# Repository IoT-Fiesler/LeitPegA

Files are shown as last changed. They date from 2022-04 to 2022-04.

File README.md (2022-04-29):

# LeitPegA
WiFi connected level meter using conductibility

To be honest, the principle is not new and there are already some descriptions of this kind of level measurement method for cisterns, wells and pump shafts on the Internet. However, what these COTS systems have in common is that the water level can only be read at fixed intervals when a button is pressed (to protect the batteries and prevent corrosion of or electrolysis on the electrodes). 

In the LeitPegA (Leitfaehigkeitsbasierte PegelAnzeige - conductivity-based level display) described here, this principle was combined with a Mega 2560 in order to enable evaluation by a microcontroller in addition to the graphic LED display via transistor circuit.
The levels are queried directly through the analog inputs of the Mega 2560. If the applied voltage exceeds a threshold value (0.7V due to the design), it evaluates this as "HIGH" and counts a variable upwards until this condition is no longer met. Then this loop breaks and the value of the variable is returned.

In addition, a potted KTY81-210 temperature sensor is installed in the cistern. These two values, the level and the water temperature, are shown on a Densitron PC-6749-AAW display in a three-second alternation.
In addition to being controlled via a button, the level can be measured using a UDP command via a WLAN connection using an ESP-01 module. In both cases, both the water level in percent and the temperature as an ASCII string are sent to the UDP server (home server) via UDP.

Another function of the LeitPegA is to switch from the cistern to the emergency feed tank if the level has dropped to 20 percent (or less). For this purpose, a solid-state relay is activated, which in turn operates a switching valve to enable water to be drawn from the emergency feed tank. To do this, the home server sends a corresponding UDP command to the LeitPegA in order to switch the relay on and off.

The device has been doing its job for almost a year now and works reliably for the most part. If, however, the water quality of the inlet is too good, i.e. the degree of pollution is too low, the resistance of the water is too high for a short time and the level returned is too low. However, this condition only lasts for a few hours, as existing deposits are loosened from the cistern walls and the resistance is reduced again.

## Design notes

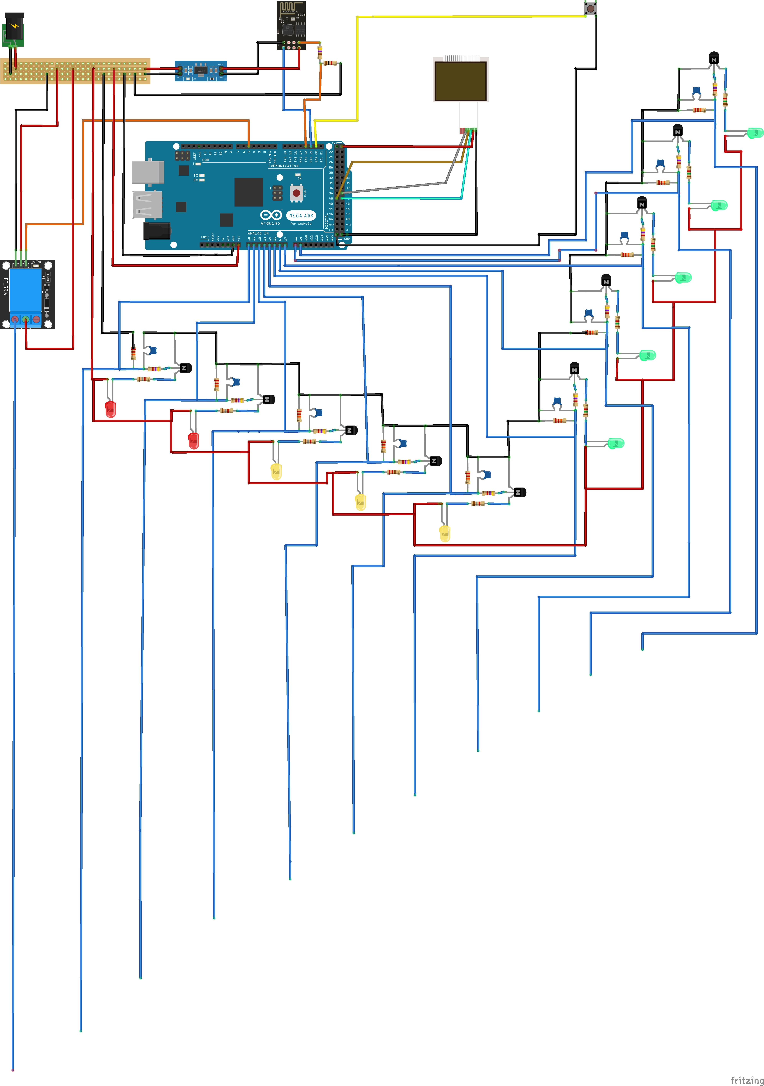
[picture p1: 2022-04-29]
LeitPegA_1_Diagram.jpg

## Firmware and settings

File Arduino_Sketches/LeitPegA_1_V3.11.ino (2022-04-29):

/*
  Number of versions:
  V1 - only push button, no display, only LEDs
  V2 - push button, LEDs and alternating display, measurement only when button is pushed
  V3 - push button, WiFi (UDP) via ESP-01 module on UART1, LEDs and display as under version 2
 
*/


/*Pin assignment

  Pins A0-A9: elektrodes level measurement
  Pin 20: push button (interrupt) for manual measurement
  Pins l8&19: UART 1 with interrupt for communication with ESP-01 module
  Pin 5: Relay
  Pin 6: Valve (via solid-state relay)
  Pin A10: KTY81-210 temperature sensor
  Pins 39-41: display


*/

//libraries
#include <Arduino.h>
#include <SPI.h>
#include <WiFiEsp.h>
#include <WiFiEspUdp.h>


int p = 0; // counting variable
int P = 0; // level in percentage
int T;  // temperature
int Offset = 5; // offset KTY81-210

//Variables and constants for Densitron LCD display

int CS = 39;
int DATA = 40;
int WR = 41;

// Pins fuer Relais
#define RELAIS 5 // Pin 5 for relay
#define VENTIL 6 // Pin 6 for valve-relay if P <= 10%

// Pin for push button
#define TASTER 20 // Pin 20 (Interrupt) for push button

// Pins for level measuring - 10 channels
#define BRAUN_10 22 //Pin 22 for brown wire & 10% level
#define WEISS_BRAUN_20 23 //Pin 23 for white (at brown) wire and 20% level
#define GELB_30 24 //Pin 24 for  yellow wire & 30% level
#define WEISS_GELB_40 25 // Pin 25 for white (at yellow) wire & 40% level
#define SCHWARZ_50 26 // Pin 26 for black wire & 50% level
#define WEISS_SCHWARZ_60 27 // Pin 27 for white (at black) wire & 60% level
#define BLAU_ROT_70 28 // Pin 28 for blue (at red) wire & 70% level
#define ROT_80 29 // Pin 29 for red wire & 80% level
#define BLAU_WEISS_90 30 // Pin 30 for blue (at white) wire & 90% level
#define WEISS_100 31 // Pinv 31 for white wire & 100% level


//Pins 11-13 for SPI or 50-52 respectively

#define CS_low()   digitalWrite(CS, LOW); delayMicroseconds(1)
#define CS_high()  delayMicroseconds(1); digitalWrite(CS, HIGH)
#define DATA(x)    if ((x)==0) digitalWrite(DATA, LOW); else digitalWrite(DATA, HIGH)
#define WR_pulse() digitalWrite(WR, LOW); delayMicroseconds(3); digitalWrite(WR, HIGH); delayMicroseconds(3)
//#define LED_on()   PORTB |= 0x20
//#define LED_off()  PORTB &= ~0x20

/* Definitions for the Densitron PC-6749 LCD glass (Pollin 120818)
   this is a 3-digit 16-segment LC display controlled by a HT1621

     glass segment mapping
   from the display datasheet  |  and how we use it

   ---------------------------
        | COM0 COM1 COM2 COM3
   -----+---------------------
   SEG0 | 1G   1K   1F   1E    \ lcd_buf[0] bit 0  1  2  3
   SEG1 | 1H   1L   1N   1D    /                4  5  6  7

   SEG2 | 1I   1M   1O   1P    \ lcd_buf[1] bit 0  1  2  3
   SEG3 | 1A   1J   1B   1C    /                4  5  6  7

   SEG4 |       X    Y    Z    \ lcd_buf[2] bit 0  1  2  3
   SEG5 | 2G   2K   2F   2E    /                4  5  6  7

   SEG6 | 2H   2L   2N   2D    \ lcd_buf[3] bit 0  1  2  3
   SEG7 | 2I   2M   2O   2P    /                4  5  6  7

   SEG8 | 2A   2J   2B   2C    \ lcd_buf[4] bit 0  1  2  3
   SEG9 | 3G   3K   3F   3E    /                4  5  6  7

   SEG10| 3H   3L   3N   3D    \ lcd_buf[5] bit 0  1  2  3
   SEG11| 3I   3M   3O   3P    /                4  5  6  7

   SEG12| 3A   3K   3B   3C    } lcd_buf[6] bit 0  1  2  3
   ---------------------------
*/

/*
   segment mapping table [digit][segment]
   entry is lcd_buf address in high nibble
   and bit number in low nibble
*/

const uint8_t segmap[3][16] =
{
  { 0x14, 0x16, 0x17, 0x07, 0x03, 0x02, 0x00, 0x04,
    0x10, 0x15, 0x01, 0x05, 0x11, 0x06, 0x12, 0x13
  },
  { 0x40, 0x42, 0x43, 0x33, 0x27, 0x26, 0x24, 0x30,
    0x34, 0x41, 0x25, 0x31, 0x35, 0x32, 0x36, 0x37
  },
  { 0x60, 0x62, 0x63, 0x53, 0x47, 0x46, 0x44, 0x50,
    0x54, 0x61, 0x45, 0x51, 0x55, 0x52, 0x56, 0x57
  }
};

/*
   font for 16-segment display
   it is sparse, hence organized as list
*/

const struct {
  char c;     /* the character */
  uint16_t s; /* 16 bits for segments A..P */
}  seg16font[] =
{ /* ABCDEFGHIJKLMNOP */
  { '1', 0b0110000001000000 },
  { '2', 0b1101110000111000 },
  { '3', 0b1111100000111000 },
  { '4', 0b0000001010111010 },
  { '5', 0b1011101000111000 },
  { '6', 0b1011111000111000 },
  { '7', 0b1000000001111010 },
  { '8', 0b1111111000111000 },
  { '9', 0b1111101000111000 },
  { '0', 0b1111111001010100 },
  { '+', 0b0000000010111010 },
  { '-', 0b0000000000111000 },
  { '*', 0b0000000111111111 },
  { '/', 0b0000000001010100 },
  { '.', 0b0000100000000000 },
  { '(', 0b0000000001000001 },
  { '$', 0b1011101010111010 },
  { ')', 0b0000000100000100 },
  { 'A', 0b1110011000111000 },
  { 'B', 0b1111100010011010 },
  { 'C', 0b1001111000000000 },
  { 'D', 0b1111100010010010 },
  { 'E', 0b1001111000110000 },
  { 'F', 0b1000011000110000 },
  { 'G', 0b1011111000001000 },
  { 'H', 0b0110011000111000 },
  { 'I', 0b1001100010010010 },
  { 'J', 0b1000100010010010 },
  { 'K', 0b0000000011010011 },
  { 'L', 0b0001111000000000 },
  { 'M', 0b0110011101010000 },
  { 'N', 0b0110011100010001 },
  { 'O', 0b1111111000000000 },
  { 'P', 0b1100011000111000 },
  { 'Q', 0b1111111000000001 },
  { 'R', 0b1100011000110001 },
  { 'S', 0b1011101000111000 },
  { 'T', 0b1000000010010010 },
  { 'U', 0b0111111000000000 },
  { 'V', 0b0000011001010100 },
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
  /* ABCDEFGHIJKLMNOP */
  { 0, 0xFFFF }
};

/*
   search character in font, return segments
   nonexisting character yields empty pattern
*/
uint16_t char2seg(char c)
{
  for (uint8_t j = 0; seg16font[j].c; j++) {
    if (seg16font[j].c == c) {
      return seg16font[j].s;
    }
  }
  return 0;
}


/*
   Send a command to the LCD controller
   ! we send the command code MSB first !
    so it matches the datasheet notation
*/
void lcd_cmd(uint8_t cmd) {
  CS_low();
  DATA(1); WR_pulse();
  DATA(0); WR_pulse();
  DATA(0); WR_pulse();
  uint8_t mask = 0x80;
  while (mask) {
    DATA(cmd & mask);
    WR_pulse();
    mask >>= 1;
  }
  DATA(1); WR_pulse();
  CS_high();
}

/*
   initialize and enable the LCD controller
*/
void lcd_init(void) {
  lcd_cmd(0b00000001); // system enable
  lcd_cmd(0b00101011); // 1/3 Bias, 4 commons
  lcd_cmd(0b00000011); // turn on LCD
}

/*
   the LCD buffer
*/
#define LCD_BUF_SIZE 7
uint8_t lcd_buf[LCD_BUF_SIZE];

/*
   clear LCD buffer
*/
void lcd_clear_buf(void)
{
  for (uint8_t i = 0; i < LCD_BUF_SIZE; i++) {
    lcd_buf[i] = 0;
  }
}

/*
   set segment bits from 'seg' for digit at position 'pos'
*/
void lcd_update_buf(uint8_t pos, uint16_t seg)
{
  uint8_t segno = 0;
  uint16_t mask = 0x8000;
  for ( ; segno < 16; segno++, mask >>= 1) {
    if (seg & mask) {
      uint8_t code = segmap[pos][segno];
      lcd_buf[code >> 4] |= 1 << (code & 7);
    }
  }
}

/*
   flush LCD buffer to the LCD controller
*/
void lcd_flush_buf(void) {
  CS_low();
  DATA(1); WR_pulse();
  DATA(0); WR_pulse();
  DATA(1); WR_pulse();

  /* address is always 0 (start of buffer) */
  DATA(0); WR_pulse();
  DATA(0); WR_pulse();
  DATA(0); WR_pulse();
  DATA(0); WR_pulse();
  DATA(0); WR_pulse();
  DATA(0); WR_pulse();

  /* bulk write the complete buffer */
  for (uint8_t i = 0; i < LCD_BUF_SIZE; i++) {
    uint8_t mask = 0x01;
    while (mask) {
      DATA(lcd_buf[i] & mask);
      WR_pulse();
      mask <<= 1;
    }
  }
  DATA(1);
  CS_high();
}


char ssid[] = "YOUR_SSID";            // your network SSID (name)
char pass[] = "YOUR_PASS";        // your network password
int status = WL_IDLE_STATUS;     // the Wifi radio's status

IPAddress ip(192, 168, 178, 91);

IPAddress RecipientIP(192, 168, 178, 56);

unsigned int RecipientPort = 9292;

unsigned int localPort = 8282;  // local port to listen on

char packetBuffer[255];          // buffer to hold incoming packet
char ReplyBuffer[] = "ACK";      // a string to send back

WiFiEspUDP Udp;

//int packetSize = Udp.parsePacket();

void setup() {

  pinMode(BRAUN_10, INPUT);
  pinMode(WEISS_BRAUN_20, INPUT);
  pinMode(GELB_30, INPUT);
  pinMode(WEISS_GELB_40, INPUT);
  pinMode(SCHWARZ_50, INPUT);
  pinMode(WEISS_SCHWARZ_60, INPUT);
  pinMode(BLAU_ROT_70, INPUT);
  pinMode(ROT_80, INPUT);
  pinMode(BLAU_WEISS_90, INPUT);
  pinMode(WEISS_100, INPUT);

  pinMode (RELAIS, OUTPUT);
  pinMode (VENTIL, OUTPUT);

  pinMode (TASTER, INPUT_PULLUP);

  // initialize serial for debugging
  Serial.begin(9600);
  // initialize serial for ESP module
  Serial1.begin(115200);
  // initialize ESP module
  WiFi.init(&Serial1);

  // check for the presence of the shield:
  if (WiFi.status() == WL_NO_SHIELD) {
    Serial.println("WiFi shield not present");
    // don't continue:
    while (true);
  }

  // attempt to connect to WiFi network
  while ( status != WL_CONNECTED) {
    Serial.print("Attempting to connect to WPA SSID: ");
    Serial.println(ssid);
    // Connect to WPA/WPA2 network
    status = WiFi.begin(ssid, pass);
  }
  
  Serial.println("Connected to wifi");
  printWifiStatus();

  Serial.println("\nStarting connection to server...");
  // if you get a connection, report back via serial:
  Udp.begin(localPort);
  
  Serial.print("Listening on port ");
  Serial.println(localPort);

  //Setup for Densitron LCD Display

  pinMode(CS,   OUTPUT);
  pinMode(WR,   OUTPUT);
  pinMode(DATA, OUTPUT);
  pinMode(LED_BUILTIN, OUTPUT);

  lcd_init();

  //delay(2000);
}

void loop () {

// if there's data available, read a packet
  int packetSize = Udp.parsePacket();
  if (packetSize) {
    Serial.print("Received packet of size ");
    Serial.println(packetSize);
    Serial.print("From ");
    IPAddress remoteIp = Udp.remoteIP();
    Serial.print(remoteIp);
    Serial.print(", port ");
    Serial.println(Udp.remotePort());

    // read the packet into packetBufffer
    int len = Udp.read(packetBuffer, 255);
    if (len > 0) {
      packetBuffer[len] = 0;
    }
    Serial.println("Contents:");
    Serial.println(packetBuffer);

    evalSerialData(packetBuffer);
  }

  else if (digitalRead(TASTER) == LOW) {  // if push button is on LOW ...

    Fuellstand();
    /*
        digitalWrite(RELAIS, HIGH); // Setze Relaisausgang auf HIGH

        p=0; // reset of level for new measurement
        P=0;

        delay(2000); // time for the capacitor to get fully charged

        for (int channel = 0; channel<=9; channel++){
          if (analogRead(channel) > 100) { //benchmark at 100, precisely with 0,7V @ 140

          int a;
          a=analogRead(channel);

          Serial.print("A");
          Serial.print(channel);
          Serial.print(":");
          Serial.println(a);

          p++;

          }
        else
        {
          break;
        }
      }
    */
    Serial.print("p=");
    Serial.println(p);

    //p=f;

    //p=Fuellstand();
    P = 10 * p;

    Serial.print("Pegelhöhe: ");
    Serial.print(P);
    Serial.println("%");

    // delay(1000);

    Temperatur();

    /*
        float X, R, T1;

        X = analogRead(A10);

        R = ((1023/X) - 1)*(1800);

        T1 = ((R - 1625)/15);

        T =(int) T1 - Offset;


      //  t = Temperatur;

        Serial.print("X=");
        Serial.println(X);
        Serial.print("R=");
        Serial.println(R);
        Serial.print("T1=");
        Serial.println(T1);
        Serial.print("Temperatur: ");
        Serial.print(T);
        Serial.println("°C");

    */

    String Ausgabe = "P" + String(P) + "%" + "," + "T" + String(T) + "G";

    //Serial3.println(Ausgabe);
    UDPsend(Ausgabe);

    /*
      Serial3.print("P");
      Serial3.print(P);
      Serial3.println("%");


      Serial3.print("T");
      Serial3.print(T);
      Serial3.println("G");
    */

    if (p == 10) {
      lcd_clear_buf();
      lcd_update_buf(0, char2seg('1'));
      lcd_update_buf(1, char2seg('0'));
      lcd_update_buf(2, char2seg('0'));
      lcd_flush_buf();
    }

    else if (p == 9) {
      lcd_clear_buf();
      lcd_update_buf(0, char2seg('P'));
      lcd_update_buf(1, char2seg('9'));
      lcd_update_buf(2, char2seg('0'));
      lcd_flush_buf();
    }
    else if (p == 8) {
      lcd_clear_buf();
      lcd_update_buf(0, char2seg('P'));
      lcd_update_buf(1, char2seg('8'));
      lcd_update_buf(2, char2seg('0'));
      lcd_flush_buf();
    }
    else if (p == 7) {
      lcd_clear_buf();
      lcd_update_buf(0, char2seg('P'));
      lcd_update_buf(1, char2seg('7'));
      lcd_update_buf(2, char2seg('0'));
      lcd_flush_buf();
    }
    else if (p == 6) {
      lcd_clear_buf();
      lcd_update_buf(0, char2seg('P'));
      lcd_update_buf(1, char2seg('6'));
      lcd_update_buf(2, char2seg('0'));
      lcd_flush_buf();
    }
    else if (p == 5) {
      lcd_clear_buf();
      lcd_update_buf(0, char2seg('P'));
      lcd_update_buf(1, char2seg('5'));
      lcd_update_buf(2, char2seg('0'));
      lcd_flush_buf();
    }
    else if (p == 4) {
      lcd_clear_buf();
      lcd_update_buf(0, char2seg('P'));
      lcd_update_buf(1, char2seg('4'));
      lcd_update_buf(2, char2seg('0'));
      lcd_flush_buf();
    }
    else if (p == 3) {
      lcd_clear_buf();
      lcd_update_buf(0, char2seg('P'));
      lcd_update_buf(1, char2seg('3'));
      lcd_update_buf(2, char2seg('0'));
      lcd_flush_buf();
    }
    else if (p == 2) {
      lcd_clear_buf();
      lcd_update_buf(0, char2seg('P'));
      lcd_update_buf(1, char2seg('2'));
      lcd_update_buf(2, char2seg('0'));
      lcd_flush_buf();
    }
    else if (p == 1) {
      lcd_clear_buf();
      lcd_update_buf(0, char2seg('P'));
      lcd_update_buf(1, char2seg('1'));
      lcd_update_buf(2, char2seg('0'));
      lcd_flush_buf();
    }

    delay (2000);

    int t1, t2;

    t1 = (int) T / 10;
    t2 = T - 10 * t1;

    lcd_clear_buf();
    lcd_update_buf(0, char2seg('T'));

    if (t1 == 2) {
      lcd_update_buf(1, char2seg('2'));
    }
    else if (t1 == 1) {
      lcd_update_buf(1, char2seg('1'));
    }
    else if (t1 == 0) {
      lcd_update_buf(1, char2seg(' '));
    }
    if (t2 == 9) {
      lcd_update_buf(2, char2seg('9'));
    }
    else if (t2 == 8) {
      lcd_update_buf(2, char2seg('8'));
    }
    else if (t2 == 7) {
      lcd_update_buf(2, char2seg('7'));
    }
    else if (t2 == 6) {
      lcd_update_buf(2, char2seg('6'));
    }
    else if (t2 == 5) {
      lcd_update_buf(2, char2seg('5'));
    }
    else if (t2 == 4) {
      lcd_update_buf(2, char2seg('4'));
    }
    else if (t2 == 3) {
      lcd_update_buf(2, char2seg('3'));
    }
    else if (t2 == 2) {
      lcd_update_buf(2, char2seg('2'));
    }
    else if (t2 == 1) {
      lcd_update_buf(2, char2seg('1'));
    }
    else if (t2 == 0) {
      lcd_update_buf(2, char2seg('0'));
    }
    lcd_flush_buf();

    delay(2000);

    digitalWrite(RELAIS, LOW);

  }
    else
  {

    Serial.print("Pegelhöhe: ");
    Serial.print(P);
    Serial.println("%");

    delay (1000);

    Serial.print("Temperatur: ");
    Serial.print(T);
    Serial.println("°C");

    if (P <= 10 && P > 0) {
      digitalWrite(VENTIL, HIGH);
      Serial.println("Notspeisung aktiviert!");
      //Serial3.println("668"); // N=6, O=6, T=8
      UDPsend("668");

      lcd_clear_buf();
      lcd_update_buf(0, char2seg('N'));
      lcd_update_buf(1, char2seg('O'));
      lcd_update_buf(2, char2seg('T'));
      lcd_flush_buf();

    }
    else {
      digitalWrite(VENTIL, LOW);
    }

    if ((millis() / 3000) % 2 == 1) {

      if (p == 10) {
        lcd_clear_buf();
        lcd_update_buf(0, char2seg('1'));
        lcd_update_buf(1, char2seg('0'));
        lcd_update_buf(2, char2seg('0'));
        lcd_flush_buf();
      }

      else if (p == 9) {
        lcd_clear_buf();
        lcd_update_buf(0, char2seg(' '));
        lcd_update_buf(1, char2seg('9'));
        lcd_update_buf(2, char2seg('0'));
        lcd_flush_buf();
      }
      else if (p == 8) {
        lcd_clear_buf();
        lcd_update_buf(0, char2seg(' '));
        lcd_update_buf(1, char2seg('8'));
        lcd_update_buf(2, char2seg('0'));
        lcd_flush_buf();
      }
      else if (p == 7) {
        lcd_clear_buf();
        lcd_update_buf(0, char2seg(' '));
        lcd_update_buf(1, char2seg('7'));
        lcd_update_buf(2, char2seg('0'));
        lcd_flush_buf();
      }
      else if (p == 6) {
        lcd_clear_buf();
        lcd_update_buf(0, char2seg(' '));
        lcd_update_buf(1, char2seg('6'));
        lcd_update_buf(2, char2seg('0'));
        lcd_flush_buf();
      }
      else if (p == 5) {
        lcd_clear_buf();
        lcd_update_buf(0, char2seg(' '));
        lcd_update_buf(1, char2seg('5'));
        lcd_update_buf(2, char2seg('0'));
        lcd_flush_buf();
      }
      else if (p == 4) {
        lcd_clear_buf();
        lcd_update_buf(0, char2seg(' '));
        lcd_update_buf(1, char2seg('4'));
        lcd_update_buf(2, char2seg('0'));
        lcd_flush_buf();
      }
      else if (p == 3) {
        lcd_clear_buf();
        lcd_update_buf(0, char2seg(' '));
        lcd_update_buf(1, char2seg('3'));
        lcd_update_buf(2, char2seg('0'));
        lcd_flush_buf();
      }
      else if (p == 2) {
        lcd_clear_buf();
        lcd_update_buf(0, char2seg(' '));
        lcd_update_buf(1, char2seg('2'));
        lcd_update_buf(2, char2seg('0'));
        lcd_flush_buf();
      }
      else if (p == 1) {
        lcd_clear_buf();
        lcd_update_buf(0, char2seg(' '));
        lcd_update_buf(1, char2seg('1'));
        lcd_update_buf(2, char2seg('0'));
        lcd_flush_buf();

      }
    }

    else {

      int t1, t2;

      t1 = (int) T / 10;
      t2 = T - 10 * t1;

      lcd_clear_buf();
      lcd_update_buf(0, char2seg('T'));

      if (t1 == 2) {
        lcd_update_buf(1, char2seg('2'));
      }
      else if (t1 == 1) {
        lcd_update_buf(1, char2seg('1'));
      }
      else if (t1 == 0) {
        lcd_update_buf(1, char2seg(' '));
      }
      if (t2 == 9) {
        lcd_update_buf(2, char2seg('9'));
      }
      else if (t2 == 8) {
        lcd_update_buf(2, char2seg('8'));
      }
      else if (t2 == 7) {
        lcd_update_buf(2, char2seg('7'));
      }
      else if (t2 == 6) {
        lcd_update_buf(2, char2seg('6'));
      }
      else if (t2 == 5) {
        lcd_update_buf(2, char2seg('5'));
      }
      else if (t2 == 4) {
        lcd_update_buf(2, char2seg('4'));
      }
      else if (t2 == 3) {
        lcd_update_buf(2, char2seg('3'));
      }
      else if (t2 == 2) {
        lcd_update_buf(2, char2seg('2'));
      }
      else if (t2 == 1) {
        lcd_update_buf(2, char2seg('1'));
      }
      else if (t2 == 0) {
        lcd_update_buf(2, char2seg('0'));
      }
      lcd_flush_buf();
    }
  }
}
//end of void loop now functions

/*
void serialEvent()
{
  int len = Udp.read(packetBuffer, 255);
  if (len > 0) {
      packetBuffer[len] = 0;
  }
    evalSerialData();
}
*/
void evalSerialData(char data[])
{
  Serial.println(data); // zum Debuggen

  if (strcmp(data, "668") == 0) {

    Fuellstand();

    delay(2000);

    P = 10 * p;

    Serial.print("Pegelhöhe:");
    Serial.print(P);
    Serial.print("%");

    /*
      Serial3.print("P");
      Serial3.print(P);
      Serial3.println("%");
    */

    Temperatur();

    Serial.print("Temperatur:");
    Serial.print(T);
    Serial.println("°C");

    /*
      Serial3.print("T");
      Serial3.print(T);
      Serial3.println("G");
    */
    String Ausgabe = "P" + String(P) + "%" + "," + "T" + String(T) + "G";

    //Serial3.println(Ausgabe);
    UDPsend(Ausgabe);

    digitalWrite(RELAIS, LOW);
  }

  else if (strcmp(data, "836") == 0) {
    digitalWrite(VENTIL, HIGH);
    Serial.println("Ventil via UART eingeschaltet");
    //Serial3.println("836");
    UDPsend("836");
  }

  else if (strcmp(data, "837") == 0) {
    digitalWrite(VENTIL, LOW);
    Serial.println("Ventil via UART ausgeschaltet");
    //Serial3.println("837");
    UDPsend("837");
  }

  else {
    Serial.println("Falsches Kommando");
    //Serial3.println ("Error");
    UDPsend("Error");
  }
}


int Fuellstand () {

  digitalWrite(RELAIS, HIGH); // Setze Relaisausgang auf HIGH

  p = 0; // Rücksetzen des Pegelstandes zur Neumessung
  P = 0;

  delay(2000); // Zeit, die der Kondensator zum Aufladen braucht, erst danach brauchbare Werte

  for (int channel = 0; channel <= 9; channel++) {
    if (analogRead(channel) > 100) { //Schwellwert 100, genau bei 0,7V etwa 140

      int a;
      a = analogRead(channel);

      Serial.print("A");
      Serial.print(channel);
      Serial.print(":");
      Serial.println(a);

      p++;

    }
    else
    {
      break;
    }
  }
  return p;
}


int Temperatur() {

  float X, R, T1;

  X = analogRead(A10);

  R = ((1023 / X) - 1) * (1800);

  T1 = ((R - 1625) / 15);

  T = (int) T1 - Offset;

  //  t = Temperatur;

  Serial.print("X=");
  Serial.println(X);
  Serial.print("R=");
  Serial.println(R);
  Serial.print("T1=");
  Serial.println(T1);
  Serial.print("Temperatur: ");
  Serial.print(T);
  Serial.println("°C");

  return T;

}

void UDPsend (String text) {
  Udp.beginPacket(RecipientIP, RecipientPort);
  Udp.print(text);
  Udp.endPacket();
  delay(10);
}

void printWifiStatus() {
  // print the SSID of the network you're attached to:
  Serial.print("SSID: ");
  Serial.println(WiFi.SSID());

  // print your WiFi shield's IP address:
  IPAddress ip = WiFi.localIP();
  Serial.print("IP Address: ");
  Serial.println(ip);

  // print the received signal strength:
  long rssi = WiFi.RSSI();
  Serial.print("signal strength (RSSI):");
  Serial.print(rssi);
  Serial.println(" dBm");
}
